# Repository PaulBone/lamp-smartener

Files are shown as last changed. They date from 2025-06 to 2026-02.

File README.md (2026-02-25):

Lamp Smartener
===============

This is the "Lamp Smartener" or "Overengineered Light Switch" it works on
USB powered LED lights.

WIP

Component selection
-------------------

 * the NE7000 can be substituted for any N-type with a Vth around 1-2 V. and
   can switch 5V,
 * The AO3400 can be substituted for any N-type that can handle 600mA of
   current, and switch 5V.  And disipate 1.25W of heat.
 * Likewise AO3401 can be substituted for any P-type that can handle 600mA of
   current and switch 5V.
 * TODO resistor tollerance
 * TODO current limiter advice.

Assembly notes
--------------

Solder the small SMD components first, it's easier to reach them before you
put the big ones in.

Solder the switches before mounting the USB ports, the usb port shield pin
will interfere with switch soldering.

Do not confuse the mosfet types.  They're different for good reasons.
p-type and n-type just arnt' compatible.  However, the NE7000 can be
substituted with more AO3400 units (probably), but not the other way around.

TODO: Add alterantive 2 and 1 port versions with the current limiter.

Mount the uC with either pin headers or directly.  for direct soldering try
holding it in place with pins/wires in the through-holes then solder the
edges.

Firmware
--------

Firmware uses the esphome framework and can be compiled with, replace
lamp-smartener.yaml with the name of the .yaml file to match your lamp
smartener, single-lamp.yaml or double-lamp.yaml.  If you're using
single-lamp.yaml check the pin names in the file match what you've soldered
on the board.

   $ mkdir /tmp/esphome
   $ docker run --rm --privileged -v "${PWD}":/config -v "/tmp/esphome:/config/.esphome" --device=/dev/ttyACM0 -it ghcr.io/esphome/esphome run lamp-smartener.yaml

Assuming you have pluged the ESP32 module into your PC and it is connected
at /dev/ttyACM0

Alternatlvely you can build and flash it in separete steps, this will erase
any wifi credentials that may be on the device, the above method does not:

   $ mkdir /tmp/esphome
   $ docker run --rm --privileged -v "${PWD}":/config -v "/tmp/esphome:/config/.esphome" -it ghcr.io/esphome/esphome compile lamp-smartener.yaml
   $ cp /tmp/esphome/build/lamp-smartener/.pioenvs/lamp-smartener/firmware.factory.bin .
   $ esptool.py write_flash 0x0 firmware.factory.bin

The device will reboot and create a new Wifi network with "Lamp Smartener"
in its name.  The password is "Overengineered Light Switch".  Connect to it
with something like your phone then visit http://192.168.4.1  Tell the page
there what wifi network you'd like it to join.

Home assistant will be able to discover it, if you use (or would like to
use) esphome's dashboard to maintain firmware updates (which is available as
a HA addon) you can adopt the device there as well.

Using the device
----------------

Each button will twoggle it's lamp (if installed) or drive automations in
Home Assistant.  In the single lamp version by default the 2nd button does
nothing directly, but it can be used to run automations in home assistant.

Pressing and holding both buttons together for 10 seconds will initiate a
factory reset, the status light will glow orange and any lamps will flash,
keep holding the buttons for another 5s to conform the factory reset,
otherwise release buttons to cancel.

Each button can be "disconnected" from its light by turning the "direct"
control switch off for that switch and lamp.  Eg if the button should run a
home assistant automation instead (which may turn on the lamp to 50%
brightness if you touch the button after midnight, and full brightness
otherwise).  The "direct" setting will persisted across reboots.

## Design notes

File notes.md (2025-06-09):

Next time
---------

 * Widen the mosfet pads for hand-soldering.
 * Make the uC's pads shorter.
 * give more space for the USB sheild pin as it bends over and collides with
   the switch pad.
 * Board is slightly asymetrical.
 * Make a new version with barrel jacks for the christmas tree.

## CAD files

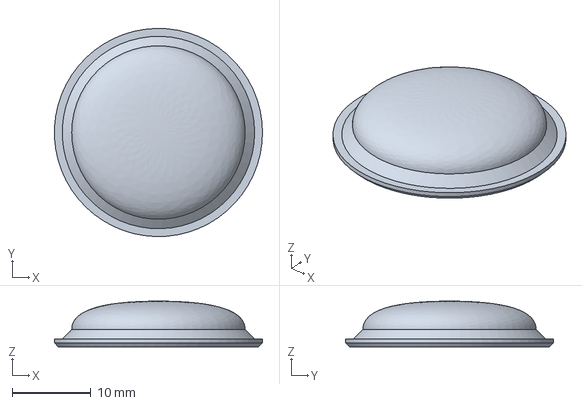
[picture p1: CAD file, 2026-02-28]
CAD/lamp_button.step
26.4 x 26.4 x 5.80 mm

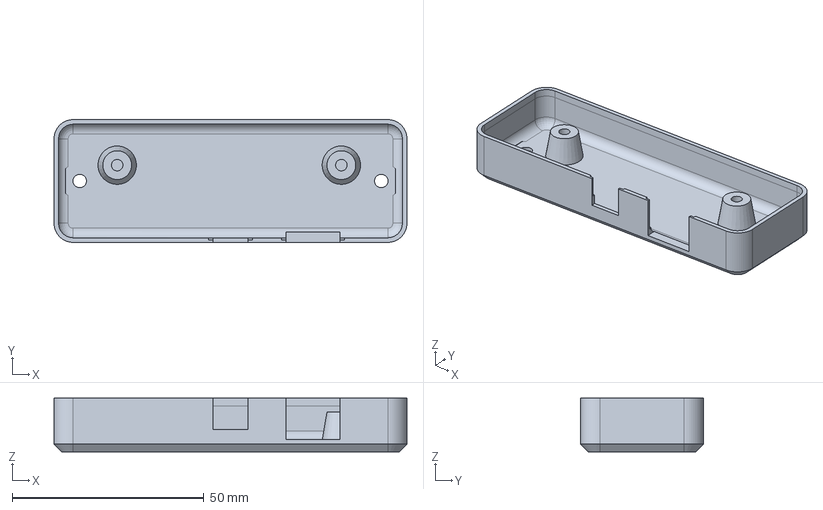
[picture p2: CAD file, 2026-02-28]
CAD/lamp_box.step
92.0 x 32.0 x 14.0 mm

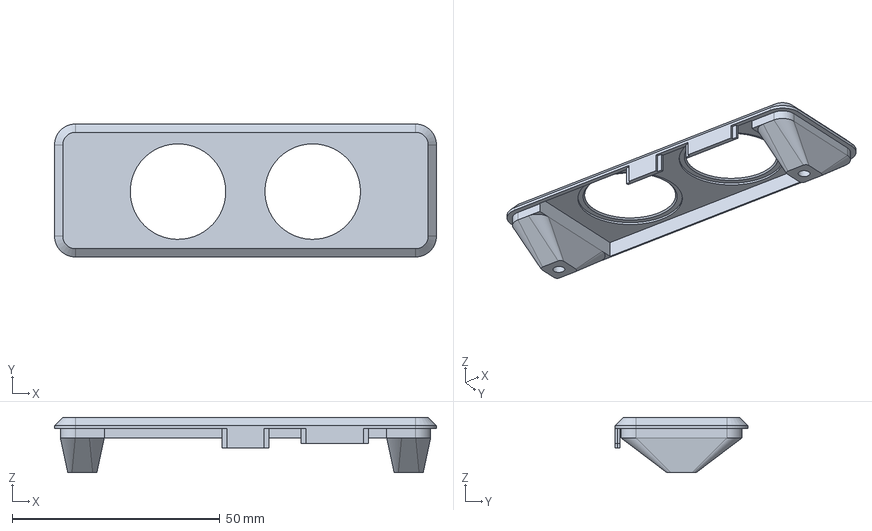
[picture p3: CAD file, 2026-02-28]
CAD/lamp_lid.step
92.0 x 32.0 x 13.3 mm

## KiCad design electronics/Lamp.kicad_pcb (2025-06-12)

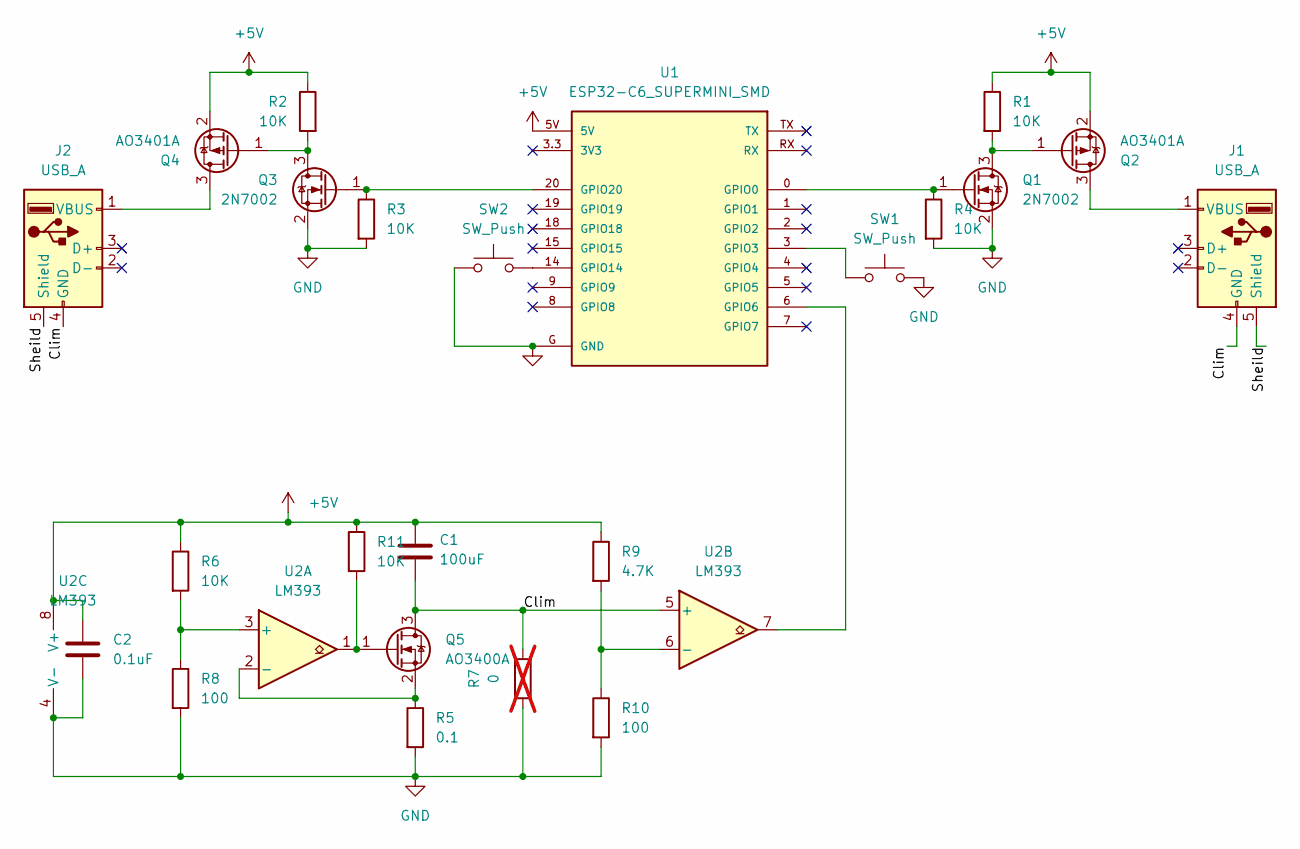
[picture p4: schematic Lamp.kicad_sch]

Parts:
C1: 100uF; CP_Elec_5x5.7
C2: 0.1uF; C_0805_2012Metric_Pad1.18x1.45mm_HandSolder
J1, J2: USB_A; USB_A_Receptacle_GCT_USB1046
Q1, Q3: 2N7002; SOT-23_Handsoldering
Q2, Q4: AO3401A; SOT-23_Handsoldering
Q5: AO3400A; SOT-23_Handsoldering
R1, R2, R3, R4, R6, R11: 10K; R_0805_2012Metric_Pad1.20x1.40mm_HandSolder
R5: 0.1; R_0805_2012Metric_Pad1.20x1.40mm_HandSolder
R7: 0; R_0805_2012Metric_Pad1.20x1.40mm_HandSolder; not fitted
R8, R10: 100; R_0805_2012Metric_Pad1.20x1.40mm_HandSolder
R9: 4.7K; R_0805_2012Metric_Pad1.20x1.40mm_HandSolder
SW1, SW2: SW_Push; SW_SMD_Tact_6mm
U1: ESP32-C6_SUPERMINI_SMD; MODULE_ESP32-C3_SUPERMINI
U2: LM393; SOP-8_3.9x4.9mm_P1.27mm

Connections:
+5V: C1.1, C2.1, Q2.2 (S), Q4.2 (S), R1.1, R2.1, R6.1, R9.1, R11.1, U1.5V, U2.8 (V+)
/Clim: C1.2, J1.4 (GND), J2.4 (GND), Q5.3 (D), R7.2, U2.5 (+)
/Sheild: J1.5 (Shield), J2.5 (Shield)
GND: C2.2, Q1.2 (S), Q3.2 (S), R3.2, R4.2, R5.2, R7.1, R8.2, R10.2, SW1.2, SW2.1, U1.G (GND), U2.4 (V-)
unnamed: J1.1 (VBUS), Q2.3 (D)
unnamed: J2.1 (VBUS), Q4.3 (D)
unnamed: Q1.3 (D), Q2.1 (G), R1.2
unnamed: Q1.1 (G), R4.1, U1.0 (GPIO0)
unnamed: Q3.3 (D), Q4.1 (G), R2.2
unnamed: Q3.1 (G), R3.1, U1.20 (GPIO20)
unnamed: Q5.1 (G), R11.2, U2.1
unnamed: Q5.2 (S), R5.1, U2.2 (-)
unnamed: SW1.1, U1.3 (GPIO3)
unnamed: U1.6 (GPIO6), U2.7
unnamed: SW2.2, U1.14 (GPIO14)
unnamed: R6.2, R8.1, U2.3 (+)
unnamed: R9.2, R10.1, U2.6 (-)

Board: 2 copper layers, 24 parts (8 on the bottom side), 17 nets, no tracks yet.

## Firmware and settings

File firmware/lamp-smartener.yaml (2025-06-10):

substitutions:
  name: lamp-smartener
  friendly_name: "Lamp Smartener"

esphome:
  name: "${name}"
  friendly_name: "${friendly_name}"
  name_add_mac_suffix: True
  project:
    name: esphome.lamp_smartener
    version: "1.1"
  on_boot: 
    then:
      script.execute: update_status

esp32:
  board: esp32-c6-devkitm-1
  variant: ESP32C6
  framework:
    type: esp-idf

# Enable logging
logger:

# Enable Home Assistant API
api:

ota:
  - platform: esphome

# This points to the public location of this yaml file.
dashboard_import:
  package_import_url: github://PaulBone/lamp-smartener/firmware/lamp-smartener.yaml
  import_full_config: false # or true


wifi:
  # Enable fallback hotspot (captive portal) in case wifi connection fails
  # Not supported in zigbee configuration.
  ap:
    ssid: "Lamp-Smartener Fallback Hotspot"
    password: "Overengineered Light Switch"

  on_connect:
    - globals.set:
        id: wifi_connected
        value: 'true'
    - script.execute: update_status
  on_disconnect:
    - globals.set:
        id: wifi_connected
        value: 'false'
    - script.execute: update_status

# Not supported with zigbee   
captive_portal:

web_server:

script:
  id: update_status
  mode: restart
  then:
    - if:
        condition:
          api.connected:
        then:
          light.turn_on:
            id: status
            brightness: 1.0
            red: 0
            green: 0
            blue: 1
        else:
        - if:
            condition: 
              lambda: |-
                return id(wifi_connected);
            then:
              light.turn_on:
                id: status
                brightness: 1.0
                red: 0
                green: 1.0
                blue: 0
            else:
              light.turn_on:
                id: status
                brightness: 1.0
                red: 1.0
                green: 0
                blue: 0
    - delay: 60s
    - light.turn_off:
        id: status

globals:
  - id: wifi_connected
    type: bool
    initial_value: "false"
    restore_value: false
  - id: direct_1
    type: bool
    initial_value: "true"
    restore_value: false
  - id: direct_2
    type: bool
    initial_value: "true"
    restore_value: false

output:
  - platform: ledc
    id: pwm_light_1
    pin: GPIO0
  - platform: ledc
    id: pwm_light_2
    pin: GPIO20

light:
  - platform: esp32_rmt_led_strip
    id: status
    internal: true
    num_leds: 1
    pin: GPIO8
    rgb_order: GRB
    chipset: ws2812
    default_transition_length: 0s
  - platform: monochromatic
    output: pwm_light_1
    name: "Light"
    id: light_1
    effects:
      - pulse:
          name: Notification
          transition_length: 1.5s
          update_interval: 1.5s
          min_brightness: 10%
          max_brightness: 100%
      - pulse:
          name: Alert
          transition_length:
            on_length: 0s
            off_length: 0.5s
          update_interval: 0.4s
          min_brightness: 0%
          max_brightness: 100%
      - flicker:
          name: Flicker
          intensity: 2.5%
          alpha: 97.5%
  - platform: monochromatic
    output: pwm_light_2
    name: "Light 2"
    id: light_2
    # Disabled on this model.
    internal: True
    effects:
      - pulse:
          name: Notification
          transition_length: 1.5s
          update_interval: 1.5s
          min_brightness: 10%
          max_brightness: 100%
      - pulse:
          name: Alert
          transition_length:
            on_length: 0s
            off_length: 0.5s
          update_interval: 0.4s
          min_brightness: 0%
          max_brightness: 100%
      - flicker:
          name: Flicker
          intensity: 2.5%
          alpha: 97.5%

binary_sensor:
  - platform: gpio
    name: "Button 1"
    id: button_1
    pin:
      number: GPIO3
      mode:
        input: true
        pullup: true
      inverted: true
    on_click:
      then:
        - if:
            condition:
              - or:
                - lambda: return id(direct_1);
                - not:
                    api.connected: 
            then:
              - light.toggle: light_1
  - platform: gpio
    name: "Button 2"
    id: button_2
    on_click:
      then:
        - if:
            condition:
              - or:
                - lambda: return id(direct_2);
                - not:
                    api.connected: 
            then:
              - light.toggle: light_2
    pin:
      number: GPIO14
      mode:
        input: true
        pullup: true
      inverted: true
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

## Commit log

2025-06-09 Initial check-in
    [Lamp.kicad_pcb, Lamp.kicad_sch]
2025-06-09 Move electronics designs into subdirectory
    [Lamp.kicad_pcb, Lamp.kicad_sch]
2025-06-10 Remove numbers from switch 1 and direct 1 names
2025-06-12 Update PCB
    [Lamp.kicad_pcb]
2025-06-13 Rename config file and set lamp pin properly
2025-06-13 Add a factory reset option to the firmware.
    [single-lamp.yaml]
2025-06-14 Add CAD file for first version
2025-06-14 Slimmer box for when board is mounted directly
2025-06-23 WIP the schematic
    [Lamp.kicad_sch]
2025-06-23 Update schamatic
    [Lamp.kicad_sch]
2026-02-28 Commit CAD .step files
    [lamp_box.step, lamp_button.step, lamp_lid.step]
